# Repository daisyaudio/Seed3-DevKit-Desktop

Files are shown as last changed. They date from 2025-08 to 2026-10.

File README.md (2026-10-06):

# Seed3 Desktop Dev Kit

Seed3 Desktop Dev Kit

## A Synth, Sampler, and Effects Platform for the Daisy Seed3

The Seed3 Desktop Dev Kit is the ultimate Daisy-powered prototyping platform for synths, samplers, and effects. Built around the Seed3, it gives you everything you need to design powerful polysynths, sequenced samplers, and rich DSP effects — all on the same hardware.

With essential audio, MIDI, CV, and control components at your fingertips, the Desktop Dev Kit makes it easy to bring your ideas to life. From stereo audio I/O to hands-on knobs and switches, it's packed with the tools you need to shape your next instrument or effect. Add USB-C connectivity, a microSD card slot, and a dedicated headphone amp, and you've got a ready-made studio workbench for turning concepts into commercial products.

---

## Contents

- [Features](#features)
- [Specifications](#specifications)
- [Getting Started](#getting-started)
- [Making Your Own Project](#making-your-own-project)
- [Hardware Reference](#hardware-reference)
- [Resources & Support](#resources--support)
- [Open-Source Hardware](#open-source-hardware)
- [License](#license)

---

## Features

| Category | Details |
| --- | --- |
| **Audio** | Stereo line-level input and output, with input jack detection |
| **Headphones** | 3.5mm headphone output with volume control |
| **MIDI** | DIN MIDI In, Out, and Thru |
| **CV & Gate** | 2 × CV inputs, 2 × gate inputs, 2 × CV outputs |
| **USB** | USB-C port for power, programming (with the Daisy bootloader), and USB serial |
| **Storage** | microSD slot (with card detect) for firmware updates, samples, presets, configuration, and more |
| **Potentiometers** | 8 × 10kΩ linear (B-taper) |
| **Buttons** | 16 × tactile switches, each with an LED |
| **Toggle Switches** | 2 × toggle switches (1 × ON-OFF-ON, 1 × ON-ON) |

## Specifications

| Parameter | Value |
| --- | --- |
| Processor module | Daisy Seed3 |
| Power | +5V via the Dev Kit's USB-C port |
| Current draw | Firmware dependent |
| Audio codec / sample rate | TAC5242 / up to 32-bit, 192kHz |
| Input impedance | 20kΩ |
| Output impedance | 100Ω |
| CV input range | -5V to +5V |
| CV output range | 0V to +5V |
| Gate input threshold | +0.4V |
| Board dimensions | 197mm × 111mm |
| MIDI connectors | 3 × 5-pin DIN (In, Out, Thru) |

## Getting Started

> [!IMPORTANT]
> This kit has two USB-C ports: one on the **Dev Kit board** (J7, above the Seed3) and one on the **Seed3 module** itself. The steps below say which one to use. Day-to-day, you power, program, and monitor the Dev Kit through the board's USB-C port.

### 1. Install the toolchain

Follow the Daisy [C++ Getting Started guide](https://docs.daisy.audio/tutorials/cpp-dev-env/). It installs the toolchain and clones [DaisyExamples](https://github.com/daisyaudio/DaisyExamples), which includes [libDaisy](https://github.com/daisyaudio/libDaisy) (hardware library) and [DaisySP](https://github.com/daisyaudio/DaisySP) (DSP library).

### 2. Update libDaisy
 
The Desktop Dev Kit template and board support are newer than the copy of libDaisy included with DaisyExamples. From your `DaisyExamples` folder, update libDaisy to its latest version, fetch its own dependencies, and rebuild it:
 
```bash
git submodule update --remote libDaisy
git -C libDaisy submodule update --init --recursive
make -C libDaisy
```
 
The first line moves libDaisy to its latest version. The second fetches libDaisy's own dependencies, such as the STM32 drivers it needs to compile. The last line rebuilds libDaisy, which is required after any update.
 
> [!CAUTION]
> Running `git submodule update --init --recursive` or `git pull --recurse-submodules` from the `DaisyExamples` folder afterwards resets libDaisy to the older version DaisyExamples was built with. If that happens, run the three commands above again.

### 3. Build the template

The starting project for this kit is [`examples/devkits/Desktop-DevKit-UI-Template`](https://github.com/daisyaudio/libDaisy/tree/master/examples/devkits/Desktop-DevKit-UI-Template). It reads every input on the Dev Kit, manages the 16 buttons, 8 pots, and LEDs with libDaisy's UI class, and prints input changes over USB serial. From the `libDaisy` folder:

```bash
cd examples/devkits/Desktop-DevKit-UI-Template
make
```

This creates `Desktop-DevKit-UI-Template.bin` in the template's `build/` folder.

### 4. Install the Daisy bootloader (one time)

The template runs from the Daisy bootloader, using the variant that accepts new programs over the **Dev Kit's** USB-C port. You install the bootloader once, through the **Seed3's** USB-C port:

1. Connect a USB-C cable from your computer to the USB-C port on the Seed3 module.
2. Hold **BOOT**, press and release **RESET**, then release **BOOT**.
3. From the template folder, run:

   ```bash
   make program-boot
   ```

   Or choose the **v6.x (external)** bootloader in the [Daisy Web Programmer](https://flash.daisy.audio/).

You don't need to reinstall the bootloader unless you switch bootloader variants, or want to program an app to the Seed3's internal flash.

### 5. Flash the template

1. Move the USB-C cable to the **Dev Kit's** USB-C port (J7, above the Seed3). This port also powers the board.
2. Press **RESET**, then **BOOT** on the Seed3. The Seed3's USR LED blinks quickly, then pulses slowly, which means it's ready to receive a program.
3. From the template folder, run:

   ```bash
   make program-dfu
   ```

   Or, in the [Daisy Web Programmer](https://flash.daisy.audio/), upload the `Desktop-DevKit-UI-Template.bin` file from the `build/` folder.

### 6. Try it out

Once flashed, the Seed3's USR LED blinks at a steady rate, and:

- Pressing a tactile switch lights its LED.
- CV Out 1 and CV Out 2 output a slow ramp and a saw wave.
- MIDI notes sent to MIDI In are echoed to MIDI Out.
- Audio at the inputs passes straight through to the outputs and the headphone jack.
- A serial monitor connected to the Dev Kit's USB-C port shows a message whenever any input changes.

## Making Your Own Project

Edits only take effect on the Dev Kit after you rebuild and reflash, so start your own project from a copy of the template.

1. Copy the `Desktop-DevKit-UI-Template` folder into your `DaisyExamples` folder and rename it, for example `DaisyExamples/MyInstrument`.
2. In the copied `Makefile`:
   - Set `TARGET` to your project name, for example `TARGET = MyInstrument`.
   - Change `LIBDAISY_DIR` to point to libDaisy from the new location: `LIBDAISY_DIR = ../libDaisy`.
   - To use DaisySP, uncomment the DaisySP line and set `DAISYSP_DIR = ../DaisySP`.
   - Keep the `APP_TYPE=BOOT_SRAM` and `BOOT_BIN` lines. They make your program run from the bootloader you installed in step 4.
3. Write your instrument in `src/main.cpp`, and adjust the button and pot handling in `src/main_page.h`. Audio is processed in `AudioCallback()`: inputs are `in[0][i]` (left) and `in[1][i]` (right), and outputs are `out[0][i]` and `out[1][i]` (see [Audio](#audio)).
4. Rebuild and flash after every change, using the Dev Kit's USB-C port:

   ```bash
   make
   make program-dfu
   ```

   Press **RESET**, then **BOOT**, before each `make program-dfu`.

> [!TIP]
> The template builds with debugging enabled (`DEBUG = 1`, `OPT = -Og`). For release builds, set `DEBUG = 0` and `OPT = -O3` in the Makefile.

## Hardware Reference

The **Ref** column lists each part's reference designator, as printed on the board's silkscreen.

### Pinout

Seed3 Desktop Dev Kit pinout

A printable [Pinout PDF](https://daisy.nyc3.cdn.digitaloceanspaces.com/products/seed-3-desktop/Seed3-Desktop-Dev-Kit-Pinout.pdf) is also available.

### Audio

| Jack | Ref | Signal | Audio Callback |
| --- | --- | --- | --- |
| Input Left | J1 | `AUDIO_IN_L` | `in[0][i]` |
| Input Right | J2 | `AUDIO_IN_R` | `in[1][i]` |
| Output Left | J3 | `AUDIO_OUT_L` | `out[0][i]` |
| Output Right | J4 | `AUDIO_OUT_R` | `out[1][i]` |
| Headphones | J5 | `AUDIO_OUT_L` / `AUDIO_OUT_R` | `out[0][i]` / `out[1][i]` (mirrors the main outputs) |
| Headphone volume | RV1 | — | Analog volume control, not read by the Seed3 |

#### Input Detection

| Jack | Ref | Signal | Seed3 Pin |
| --- | --- | --- | --- |
| Input Left | J1 | `LEFT_DETECT` | D16 |
| Input Right | J2 | `RIGHT_DETECT` | D17 |

### Potentiometers (8-channel multiplexer)

The eight pots are read through a single ADC pin via an 8-channel analog multiplexer (U12). Set the select lines A/B/C to choose a channel, then read `POT_MUX`.

| Signal | Seed3 Pin |
| --- | --- |
| `POT_MUX` (ADC) | D15 |
| `MUX_CTRL_A` | D24 |
| `MUX_CTRL_B` | D25 |
| `MUX_CTRL_C` | D26 |

| Pot | Ref | Mux Channel |
| --- | --- | --- |
| Potentiometer 1 | VR1 | `MUX_CH_0` |
| Potentiometer 2 | VR2 | `MUX_CH_1` |
| Potentiometer 3 | VR3 | `MUX_CH_2` |
| Potentiometer 4 | VR4 | `MUX_CH_3` |
| Potentiometer 5 | VR5 | `MUX_CH_4` |
| Potentiometer 6 | VR6 | `MUX_CH_5` |
| Potentiometer 7 | VR7 | `MUX_CH_6` |
| Potentiometer 8 | VR8 | `MUX_CH_7` |

### Tactile Switches (2 × shift register)

The 16 tactile switches are read through two daisy-chained shift registers (U4, U5).

| Signal | Seed3 Pin |
| --- | --- |
| `SR_LATCH` | D9 |
| `SR_CLK` | D8 |
| `SR_DATA` | D10 |

Switches S1–S16 map to `TAC_SW1`–`TAC_SW16`, arranged in two rows of eight:

| | | | | | | | |
| --- | --- | --- | --- | --- | --- | --- | --- |
| S1 | S2 | S3 | S4 | S5 | S6 | S7 | S8 |
| S9 | S10 | S11 | S12 | S13 | S14 | S15 | S16 |

### LEDs (I²C LED driver)

The 16 LEDs (`LED_1`–`LED_16`, refs D1–D16) sit in the same two rows of eight as the tactile switches, each LED just above its switch (D1 above S1, through D16 above S16), and are driven by a PCA9685 LED driver (U8) over I²C.

| Signal | Seed3 Pin |
| --- | --- |
| `I2C_SCL` | D11 |
| `I2C_SDA` | D12 |

> [!NOTE]
> LED refs D1–D16 are component reference designators, not Seed3 pins.

### Toggle Switches

| Switch | Ref | Signal | Seed3 Pin | Type |
| --- | --- | --- | --- | --- |
| Toggle switch 1 | SW17 | `TOG_1` | D19 | ON-ON |
| Toggle switch 2 | SW18 | `TOG_2_A` / `TOG_2_B` | D28 / D27 | ON-OFF-ON (3-position, two pins) |

### CV & Gates

| Jack | Ref | Signal | Seed3 Pin |
| --- | --- | --- | --- |
| Gate In 1 | J_GATE_IN1 | `GATE_IN1` | D0 |
| Gate In 2 | J_GATE_IN2 | `GATE_IN2` | D18 |
| CV In 1 | J_CV_IN_1 | `CV_IN_1` | D20 |
| CV In 2 | J_CV_IN_2 | `CV_IN_2` | D21 |
| CV Out 1 | J_CV_OUT_1 | `CV_OUT_1` | D23 (DAC channel 1) |
| CV Out 2 | J_CV_OUT_2 | `CV_OUT_2` | D22 (DAC channel 2) |

### MIDI

| Jack | Ref | Signal | Seed3 Pin | Direction |
| --- | --- | --- | --- | --- |
| MIDI Out | J11 | `MIDI_TX` | D13 | Out |
| MIDI In | J10 | `MIDI_RX` | D14 | In |
| MIDI Thru | J8 | `MIDI_RX` | D14 | Mirrors MIDI In |

### microSD (SDMMC, 4-bit)

| Signal | Seed3 Pin |
| --- | --- |
| `SDMMC_CK` | D6 |
| `SDMMC_CMD` | D5 |
| `SDMMC_D0` | D4 |
| `SDMMC_D1` | D3 |
| `SDMMC_D2` | D2 |
| `SDMMC_D3` | D1 |
| `SDMMC_DETECT` | D7 |

### USB-C

The Dev Kit's USB-C port (J7) powers the board and connects to the Seed3's external USB peripheral. It is separate from the USB-C port on the Seed3 module.

| Signal | Seed3 Pin |
| --- | --- |
| `USB_OTG_HS_N` | D29 |
| `USB_OTG_HS_P` | D30 |

## Resources & Support

- **Product Page:** [Seed3 Desktop Dev Kit](https://daisy.audio/products/seed-3-desktop-dev-kit)
- **Documentation:** [docs.daisy.audio](https://docs.daisy.audio/product/Seed3-Desktop-Dev-Kit/)
- **Community Forum:** [community.daisy.audio](https://community.daisy.audio)
- **Discord:** [Daisy Discord](https://discord.gg/ByHBnMtQTR)
- **Issues:** Report bugs or hardware errata via this repository's [Issues](../../issues) tab.

### Design Files

- [Schematic (PDF)](https://daisy.nyc3.cdn.digitaloceanspaces.com/products/seed-3-desktop/ES-Seed3-DevKit-Desktop-Rev3.pdf)
- [Bill of Materials (CSV)](https://daisy.nyc3.cdn.digitaloceanspaces.com/products/seed-3-desktop/Seed3-DevKit-Desktop_Rev4-bom.csv)
- [Pinout (PDF)](https://daisy.nyc3.cdn.digitaloceanspaces.com/products/seed-3-desktop/Seed3-Desktop-Dev-Kit-Pinout.pdf)
- [KiCad Design Files](https://github.com/daisyaudio/Seed3-DevKit-Desktop/releases/latest)

---

## Open-Source Hardware

Open Source Hardware logo

The Desktop Dev Kit is open-source hardware, built to the [Open Source Hardware Definition](https://www.oshwa.org/definition/) published by the Open Source Hardware Association (OSHWA). The schematics, PCB layouts, bill of materials, and KiCad source files are published so that you can study, modify, manufacture, and sell your own designs based on them.

## License

Copyright © 2026 Qu-Bit Electronix, Inc. (dba Daisy)

The hardware design files in this repository are licensed under the **CERN Open Hardware Licence Version 2 – Permissive** ([CERN-OHL-P-2.0](https://ohwr.org/cern_ohl_p_v2.pdf)).

Subject to the terms of that licence, you may:

- Use, study, copy, modify, and distribute these designs and any products made from them.
- Incorporate these designs, in whole or in part, into closed-source and commercial products.

These designs are provided "as is", without warranty of any kind, express or implied. See [LICENSE](LICENSE.txt) for the full licence text, including the disclaimer of warranty and limitation of liability.

Firmware and software, including [libDaisy](https://github.com/daisyaudio/libDaisy) and [DaisySP](https://github.com/daisyaudio/DaisySP), are licensed separately under the terms included in their respective repositories.

SPDX-License-Identifier: CERN-OHL-P-2.0

### Trademarks

DAISY® is a trademark of Qu-Bit Electronix, Inc., registered in the United States. CERN-OHL-P-2.0 grants a license to the copyright and related rights in these designs. It does not grant any right or license to use the DAISY name, logos, product names, or other trademarks of Qu-Bit Electronix, Inc.

Products, derivative designs, and related materials made from these designs may not:

- Use the DAISY name or logo, or any confusingly similar name or mark, in a product name, model number, brand, domain name, or marketing material.
- Reproduce the DAISY name or logo on a PCB silkscreen, front panel, enclosure, packaging, or documentation, except where needed to keep the required licence notices.
- State or imply that the product is made, endorsed, sponsored, certified, or supported by Qu-Bit Electronix, Inc.

You may make truthful, factual statements about compatibility or origin, such as "based on the Seed3 Desktop Dev Kit design" or "compatible with the Daisy Seed3", provided the statement does not suggest affiliation or endorsement. If you redistribute or sell products derived from these designs, remove the DAISY name and logo from the silkscreen and other artwork before manufacture.

For trademark licensing or permission requests, contact Qu-Bit Electronix, Inc. through [daisy.audio/pages/support](https://daisy.audio/pages/support).

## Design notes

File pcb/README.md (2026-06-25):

# Changelog

## Rev4

- Added missing diode to MIDI input circuit

## Rev3

- Removed components from audio input circuit that introduced noise: R64, R65, D21, D22, D23, D24
- Connected switching connection on CV Input jacks to GND to prevent idling at non-0V
- Added silk screen indications for software mapping to Daisy for all pins/peripheral information.
- Swapped CV out 1 and 2 from the seed so that the software channel matches the hardware label

## Rev2

- Fixed INH pin on CD4051 to be properly connected to GND.
- Fixed LED OE pin on PCA9685 to be properly connected to GND so it is always on.
- Huge rework of power supply circuit
  - USB +5V now goes to a boost to generate +9V
  - +9V is split to provide DSY_VIN, +9V_A
  - +9V_A now powers an LD1117-5V to generate a more reliable +5V (for headphones, DAC MCP6002, and CV input ref voltage)
- AREF_+2V5 has been replaced with +4v5 generated from buffered +9V_A
- Added clamping diodes (1N5817) to the audio input detection to help protect from higher level audio potentially damaging the GPIO.
- Added explicit, "C0G" in value field for the few caps that should be that
- Added series AC coupling cap to input of the line out circuit (to better match, the already tested Pedal circuit).
- Added series 100R resistor to the output of the line out circuit
- Added a 10k to GND after the output coupling cap so the HPF is fixed (once again, to match the pedal circuit)
- Updated rev text to rev2
- Moved Open hardware logo to below the CV/Gate jacks (new beefy power circuits occupied previous location)
- Added some more vias to GND where it makes sense.
- Updated QR code to point to: <https://electro-smith.com/seed3-desktop-redirect>

## Rev1

Original Hardware

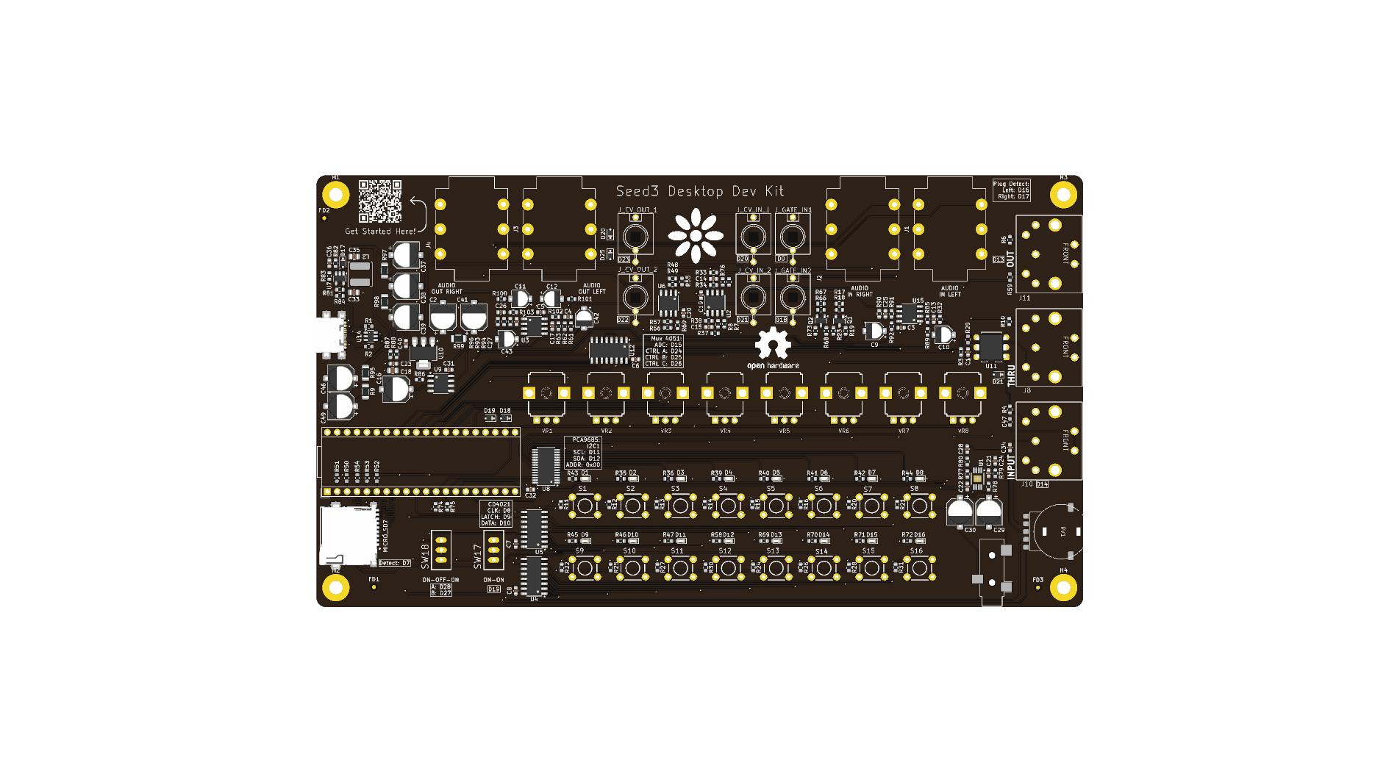
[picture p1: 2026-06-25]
pcb/ES-Seed3-Devkit-Desktop-Rev4/review/2026-06-18/board-render/render_top.png

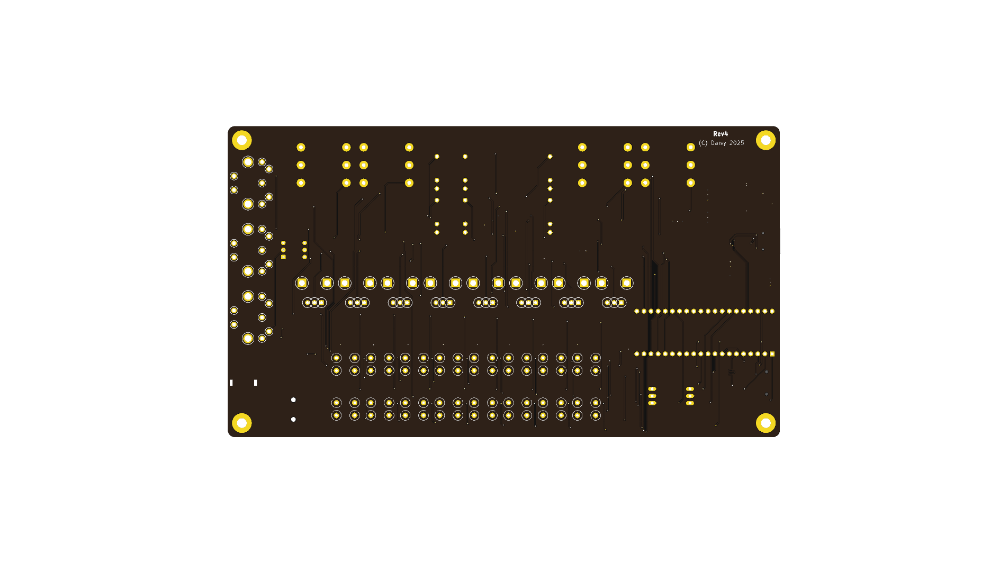
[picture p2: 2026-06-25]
pcb/ES-Seed3-Devkit-Desktop-Rev4/review/2026-06-18/board-render/render_bottom.png

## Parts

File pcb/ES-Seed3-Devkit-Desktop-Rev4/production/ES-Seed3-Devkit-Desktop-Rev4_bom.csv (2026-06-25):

Value | Reference | Footprint | Qty | AVL_Part_Number
 | J_CV_IN_1,J_CV_IN_2,J_CV_OUT_1,J_CV_OUT_2,J_GATE_IN1,J_GATE_IN2 | Electrosmith-Interface:S_JACK | 6
0R | R84 | Resistor_SMD:R_0603_1608Metric | 1 | 0R R0603
1NF | C14,C15 | Capacitor_SMD:C_0603_1608Metric | 2 | 1NF C0603
1UF | C21 | Capacitor_SMD:C_0603_1608Metric | 1 | 1UF C0603
3R3 | R9,R95,R97,R98,R99 | Resistor_SMD:R_1206_3216Metric | 5 | 3R3
10UF MLCC | C18,C33,C35 | Capacitor_SMD:C_0805_2012Metric | 3 | 10UF MLCC C0805
10R | R6,R10,R29,R59 | Resistor_SMD:R_0603_1608Metric | 4 | 10R R0603
10UF | C9,C10,C11,C12,C42,C43 | Capacitor_SMD:CP_Elec_4x5.8 | 6 | 10UF
100NF | C1,C3,C5,C6,C7,C8,C19,C20,C22,C23,C31,C32,C34,C40,C47 | Capacitor_SMD:C_0603_1608Metric | 15 | 100NF C0603
100R | R23,R55,R60,R73,R102,R103 | Resistor_SMD:R_0603_1608Metric | 6 | 100R R0603
100UF | C2,C16,C29,C30,C37,C38,C39,C41,C46,C49 | Capacitor_SMD:CP_Elec_6.3x7.7 | 10 | 100UF
220R | R4 | Resistor_SMD:R_0603_1608Metric | 1 | 220R R0603
270R | R3 | Resistor_SMD:R_0603_1608Metric | 1 | 270R R0603
470NF | C24,C28 | Capacitor_SMD:C_0603_1608Metric | 2 | 470NF C0603
750R | R62,R93 | Resistor_SMD:R_0603_1608Metric | 2 | 750R R0603
1K | R89,R92 | Resistor_SMD:R_0603_1608Metric | 2 | 1K R0603
2K | R35,R36,R39,R40,R41,R42,R43,R44,R45,R46,R47,R58,R69,R70,R71,R72,R74,R75 | Resistor_SMD:R_0603_1608Metric | 18 | 2K R0603
5K1 | R1,R2 | Resistor_SMD:R_0603_1608Metric | 2 | 5K1 R0603
10K | R11,R12,R13,R14,R15,R16,R19,R20,R21,R22,R24,R25,R26,R27,R28,R30,R31,R61,R68,R83,R85,R86,R87,R88,R91,R96,R100,R101 | Resistor_SMD:R_0603_1608Metric | 28 | 10K R0603
20K | R32,R63,R90,R94 | Resistor_SMD:R_0603_1608Metric | 4 | 20K R0603
22K | R79,R80 | Resistor_SMD:R_0603_1608Metric | 2 | 22K R0603
33K | R5,R7,R34,R38,R77,R78 | Resistor_SMD:R_0603_1608Metric | 6 | 33K R0603
47K | R50,R51,R52,R53,R54 | Resistor_SMD:R_0603_1608Metric | 5 | 47K R0603
62K | R49,R57,R82 | Resistor_SMD:R_0603_1608Metric | 3 | 62K R0603
100K | R8,R17,R33,R37,R66,R76 | Resistor_SMD:R_0603_1608Metric | 6 | 100K R0603
120K | R48,R56 | Resistor_SMD:R_0603_1608Metric | 2 | 120K R0603
1M | R18,R67,R81 | Resistor_SMD:R_0603_1608Metric | 3 | 1M R0603
470PF | C4,C26 | Capacitor_SMD:C_0603_1608Metric | 2 | 470PF C0603
560PF | C36 | Capacitor_SMD:C_0603_1608Metric | 1 | 560PF C0603
1N5817WS | D17,D18,D19,D20,D21,D25 | Diode_SMD:D_SOD-323F | 6 | 1N5817WS
330PF C0G | C13,C25 | Capacitor_SMD:C_0603_1608Metric | 2 | 330PF C0G C0603
470PF C0G | C17,C27 | Capacitor_SMD:C_0603_1608Metric | 2 | 470PF C0G C0603
6.8uH 2.9A | L2 | Inductor_SMD:L_TDK_VLS6045EX_VLS6045AF | 1 | 6.8uH 2.9A
AudioJack3_Switch | J1,J2,J3,J4 | Connector_Audio:Jack_6.35mm_Neutrik_NMJ6HCD2_Horizontal | 4 | AudioJack3_Switch
AudioJack3_Switch_HEADPHONE | J5 | Connector_Audio:Jack_3.5mm_CUI_SJ-3523-SMT_Horizontal | 1 | AudioJack3_Switch_HEADPHONE
CD4051B | U12 | Package_SO:SOIC-16_3.9x9.9mm_P1.27mm | 1 | CD4051B
CD4021BM96 | U4,U5 | Package_SO:SOIC-16_3.9x9.9mm_P1.27mm | 2 | CD4021BM96
DIN_MIDI_5P | J8,J10,J11 | parts-for-kicad:57PC5F | 3 | DIN_MIDI_5P
Electrosmith_Daisy_Seed_Rev4 | A1 | Module:Electrosmith_Daisy_Seed | 1 | Electrosmith_Daisy_Seed_Rev4
H11L1 | U11 | Package_DIP:DIP-6_W7.62mm | 1 | H11L1
LD1117S50TR_SOT223 | U10 | Package_TO_SOT_SMD:SOT-223-3_TabPin2 | 1 | LD1117S50TR_SOT223
LED | D1,D2,D3,D4,D5,D6,D7,D8,D9,D10,D11,D12,D13,D14,D15,D16 | LED_SMD:LED_0603_1608Metric | 16 | LED
LMR62421XMF | U7 | Package_TO_SOT_SMD:SOT-23-5 | 1 | LMR62421XMF
MCP6002-xSN | U2,U6,U9 | Package_SO:SOIC-8_3.9x4.9mm_P1.27mm | 3 | MCP6002-xSN
MMBT3904 | Q1,Q2 | Package_TO_SOT_SMD:SOT-23 | 2 | MMBT3904
OPA1652 | U3,U15 | Package_SO:SOIC-8_3.9x4.9mm_P1.27mm | 2 | OPA1652
P-10K-B-R | VR1,VR2,VR3,VR4,VR5,VR6,VR7,VR8 | parts-for-kicad:9MM_SNAP-IN_POT_SILK | 8 | P-10K-B-R
PCA9685PW | U8 | Package_SO:TSSOP-28_4.4x9.7mm_P0.65mm | 1 | PCA9685PW
PTH Mini Button | S1,S2,S3,S4,S5,S6,S7,S8,S9,S10,S11,S12,S13,S14,S15,S16 | parts-for-kicad:TL1105SPF250Q_SILK | 16 | PTH Mini Button
R_Potentiometer_Dual_Separate | RV1 | shnsly:Rotary Pot RK10J | 1 | R_Potentiometer_Dual_Separate
TF-01A | MICRO_SD7 | TF-01A:TF-01A | 1 | TF-01A
TOGGLE_ON-ON_PIP3 | SW17 | Electrosmith-Interface:TOGGLE_ON-ON | 1 | TOGGLE_ON-ON_PIP3
TOGGLE_ON_OFF_ON_PIP2 | SW18 | Electrosmith-Interface:TOGGLE_ON_OFF_ON | 1 | TOGGLE_ON_OFF_ON_PIP2
TPA6110A2DGN | U1 | Package_SO:HVSSOP-8-1EP_3x3mm_P0.65mm_EP1.57x1.89mm | 1 | TPA6110A2DGN
USB4110GFA | J7 | USB4110GFA:GCT_USB4110GFA | 1 | USB4110GFA
USBLC6-2SC6 | U14 | Package_TO_SOT_SMD:SOT-23-6 | 1 | USBLC6-2SC6

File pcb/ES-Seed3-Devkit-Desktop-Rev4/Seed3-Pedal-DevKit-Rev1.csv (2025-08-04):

Id | Designator | Footprint | Quantity | Designation | Supplier and ref
1 | R46,R8,R48,R13,R72,R27,R76,R16,R55 | R_0603_1608Metric | 9 | 100R
2 | FD3,FD1,FD2 | Fiducial_1mm_Mask2mm | 3 | FIDUCIAL
3 | C46 | C_0603_1608Metric | 1 | 10NF
4 | R61,R57,R62,R29,R28,R59,R63 | R_0603_1608Metric | 7 | 10R
5 | SW4,SW3 | TL3301SPF160QJ | 2 | SMT Mini Button
6 | C30,C9,C28,C8 | C_0603_1608Metric | 4 | 1NF
7 | R77,R26,R56,R22,R14,R69,R65,R5,R19,R17,R68,R70,R64 | R_0603_1608Metric | 13 | 10K
8 | Q1,Q5 | SOT-23 | 2 | 3904
9 | C5,C38 | C_0603_1608Metric | 2 | 100PF
10 | C31,C47,C33,C20,C2,C25,C34,C22,C4,C16,C17,C1 | C_0603_1608Metric | 12 | 100NF
11 | R50,R51,R52,R54,R53 | R_0603_1608Metric | 5 | 47K
12 | C27,C24,C43,C36,C14,C21,C39,C13,C41,C23 | CP_Elec_6.3x7.7 | 10 | 100UF
13 | U3,U10,U9 | SOIC-8_5.275x5.275mm_P1.27mm | 3 | OPA1652
14 | FB2,FB5,FB8,FB1,FB9,FB10,FB3,FB4,FB7 | R_0603_1608Metric | 9 | FERRITE_BEAD_0603
15 | R2,R1 | R_0603_1608Metric | 2 | 5K1
16 | H1,H2,H3,H4 | MountingHole_3.5mm_Pad | 4 | MOUNT-PAD-ROUND3.5
17 | LOGO1 | OSHW-LOGO-L_TEXT | 1 | OSHW-LOGO
18 | J5,J2,J6,J3,J4 | TRS_JACK_WQP-PJ609B | 5 | JACK_TRS_SWITCHING
19 | C12,C37 | C_0603_1608Metric | 2 | 33NF
20 | J11,J1,J10 | 57PC5F | 3 | DIN_MIDI_5P
21 | VR3,VR5,VR1,VR4,VR6,VR2 | 9MM_SNAP-IN_POT_SILK_PIP | 6 | P-10K-B-R-PIP
22 | R44,R9,R43,R10,R24,R23,R40,R25 | R_0603_1608Metric | 8 | 2K
23 | R60 | R_0603_1608Metric | 1 | 20K
24 | SW2,SW6 | TOGGLE_SILK_PIP3 | 2 | TOGGLE_ON-ON_PIP3
25 | U8 | SOT-223-3_TabPin2 | 1 | LD1117-5V
26 | R21,R71 | R_0603_1608Metric | 2 | 4K7
27 | R7,R15,R18 | R_0603_1608Metric | 3 | 1M
28 | C29,C48,C10,C42,C7,C35,C6,C3 | CP_Elec_4x5.8 | 8 | 10uF
29 | D6,D5 | D_SOD-323 | 2 | NSR1020MW2T3G
30 | LED1 | LED_D5.0mm | 1 | LED
31 | R11,R74 | R_0603_1608Metric | 2 | 15K
32 | A1 | Electrosmith_Daisy_Seed | 1 | Electrosmith_Daisy_Seed_Rev4
33 | C11,C32 | C_0603_1608Metric | 2 | 270PF
34 | U6,U5 | RELAY-SMD_G6K-2F-Y | 2 | G6K-2F-Y-TR DC3
35 | C26,C15 | C_0805_2012Metric | 2 | 10UF
36 | R75,R12 | R_0603_1608Metric | 2 | 24K
37 | R58,R20 | R_0603_1608Metric | 2 | 3K3
38 | D3,D4 | D_SOD-323 | 2 | 1N4148
39 | U11 | DIP-6_W7.62mm | 1 | H11L1
40 | FSW_1,FSW_2 | S02P | 2 | M12 SPST Footswitch Assembly
41 | U14 | SOT-23-6 | 1 | USBLC6-2SC6
42 | C55 | C_0603_1608Metric | 1 | 1UF
43 | SW1 | TOGGLE_SILK_PIP3 | 1 | TOGGLE_ON_OFF_ON_PIP2
44 | R3 | R_0603_1608Metric | 1 | 270R
45 | C18,C19 | CP_Elec_4x5.8 | 2 | 10UF
46 | LED2 | LED_D5.0mm-4_RGB_Wide_Pins | 1 | LED_RKBG
47 | U1 | SOIC-8_5.275x5.275mm_P1.27mm | 1 | MCP6002-xSN
48 | L2 | SDR0805 | 1 | SDR0805-102KL
49 | U7 | MEM2061-01-188-00-A_GCT | 1 | MICRO_SD_CARD
50 | J8 | BarrelJack_Wuerth_6941xx301002 | 1 | Barrel_Jack_Switch
51 | U4 | USB-C-SMD_G-SWITCH_GT-USB-7010ASV | 1 | GT-USB-7010ASV
52 | R4 | R_0603_1608Metric | 1 | 220R

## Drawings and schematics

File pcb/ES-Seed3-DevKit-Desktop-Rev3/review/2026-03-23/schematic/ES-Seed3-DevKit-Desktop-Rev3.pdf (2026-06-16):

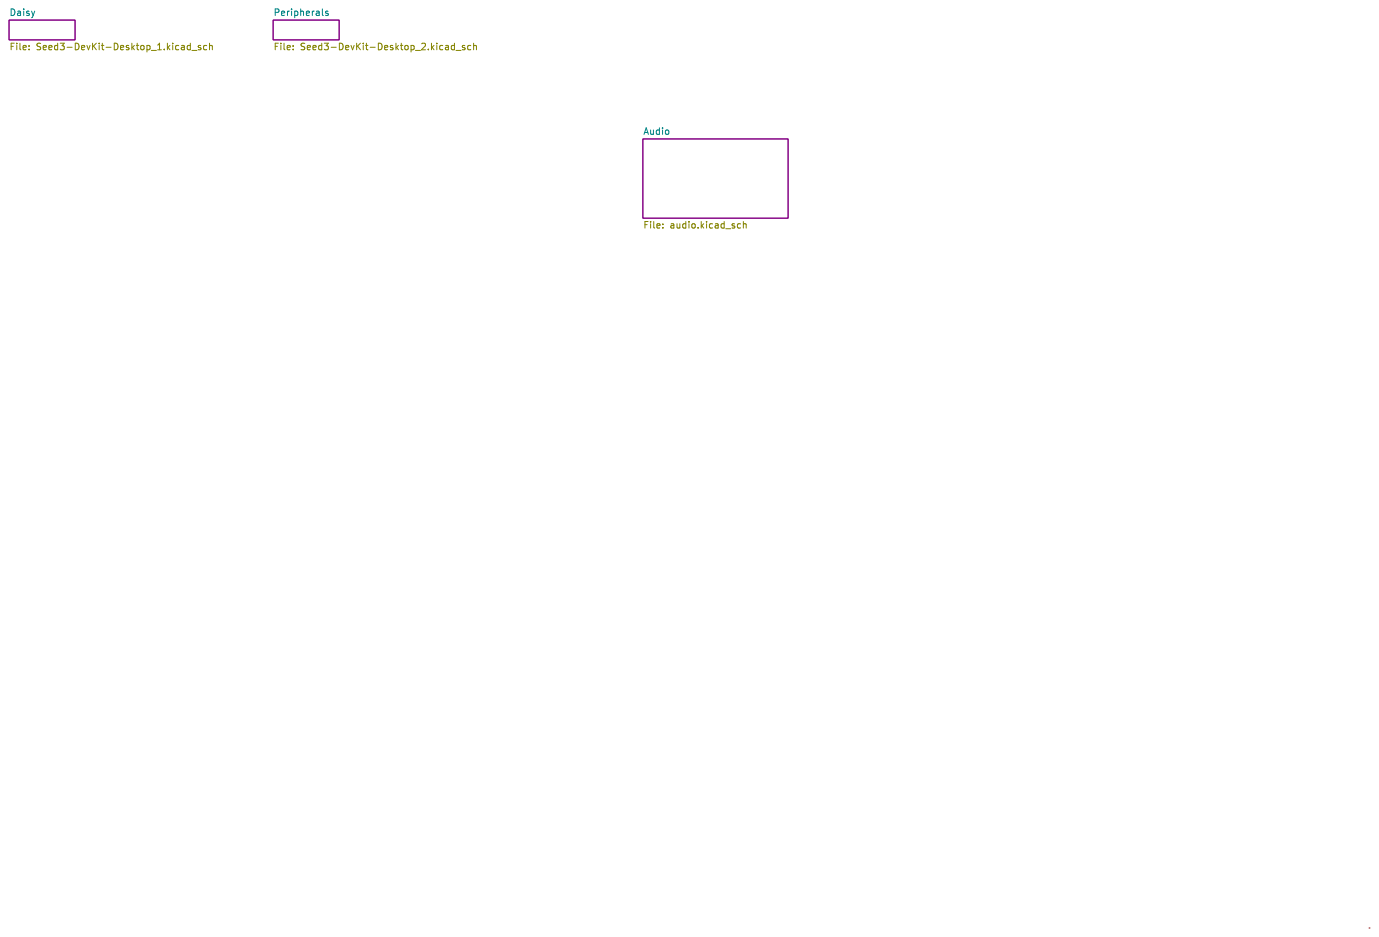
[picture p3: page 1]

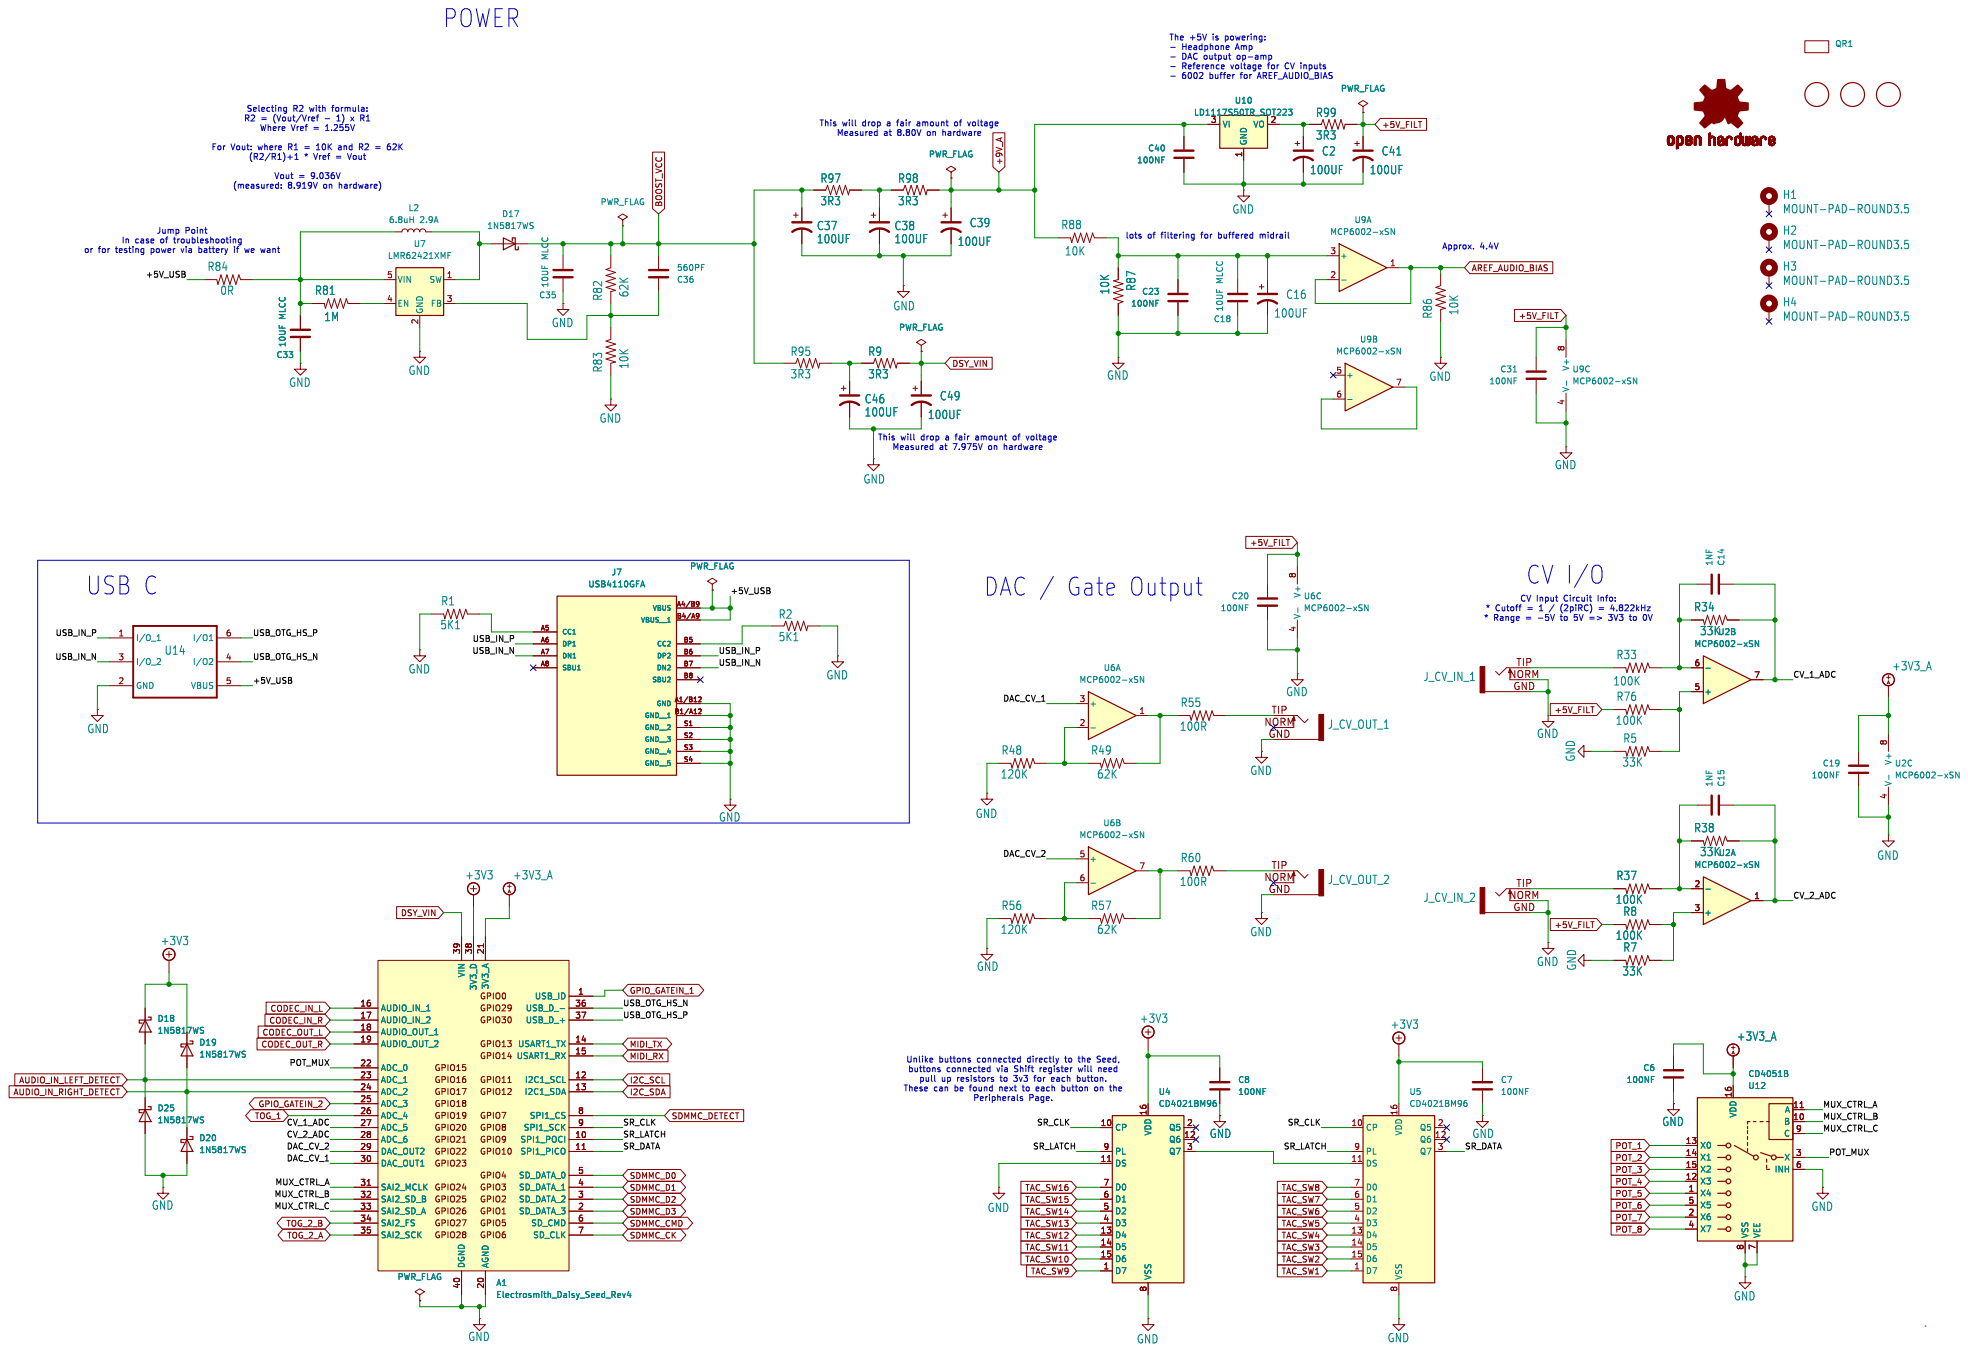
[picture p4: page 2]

The +5V is powering: - Headphone Amp
TAC_SW14 +9V_A

- DAC output op-amp
- Reference voltage for CV inputs
- 6002 buffer for AREF_AUDIO_BIAS

For Vout: where R1 = 10K and R2 = 62K

In case of troubleshooting

or for testing power via battery if we want USB C

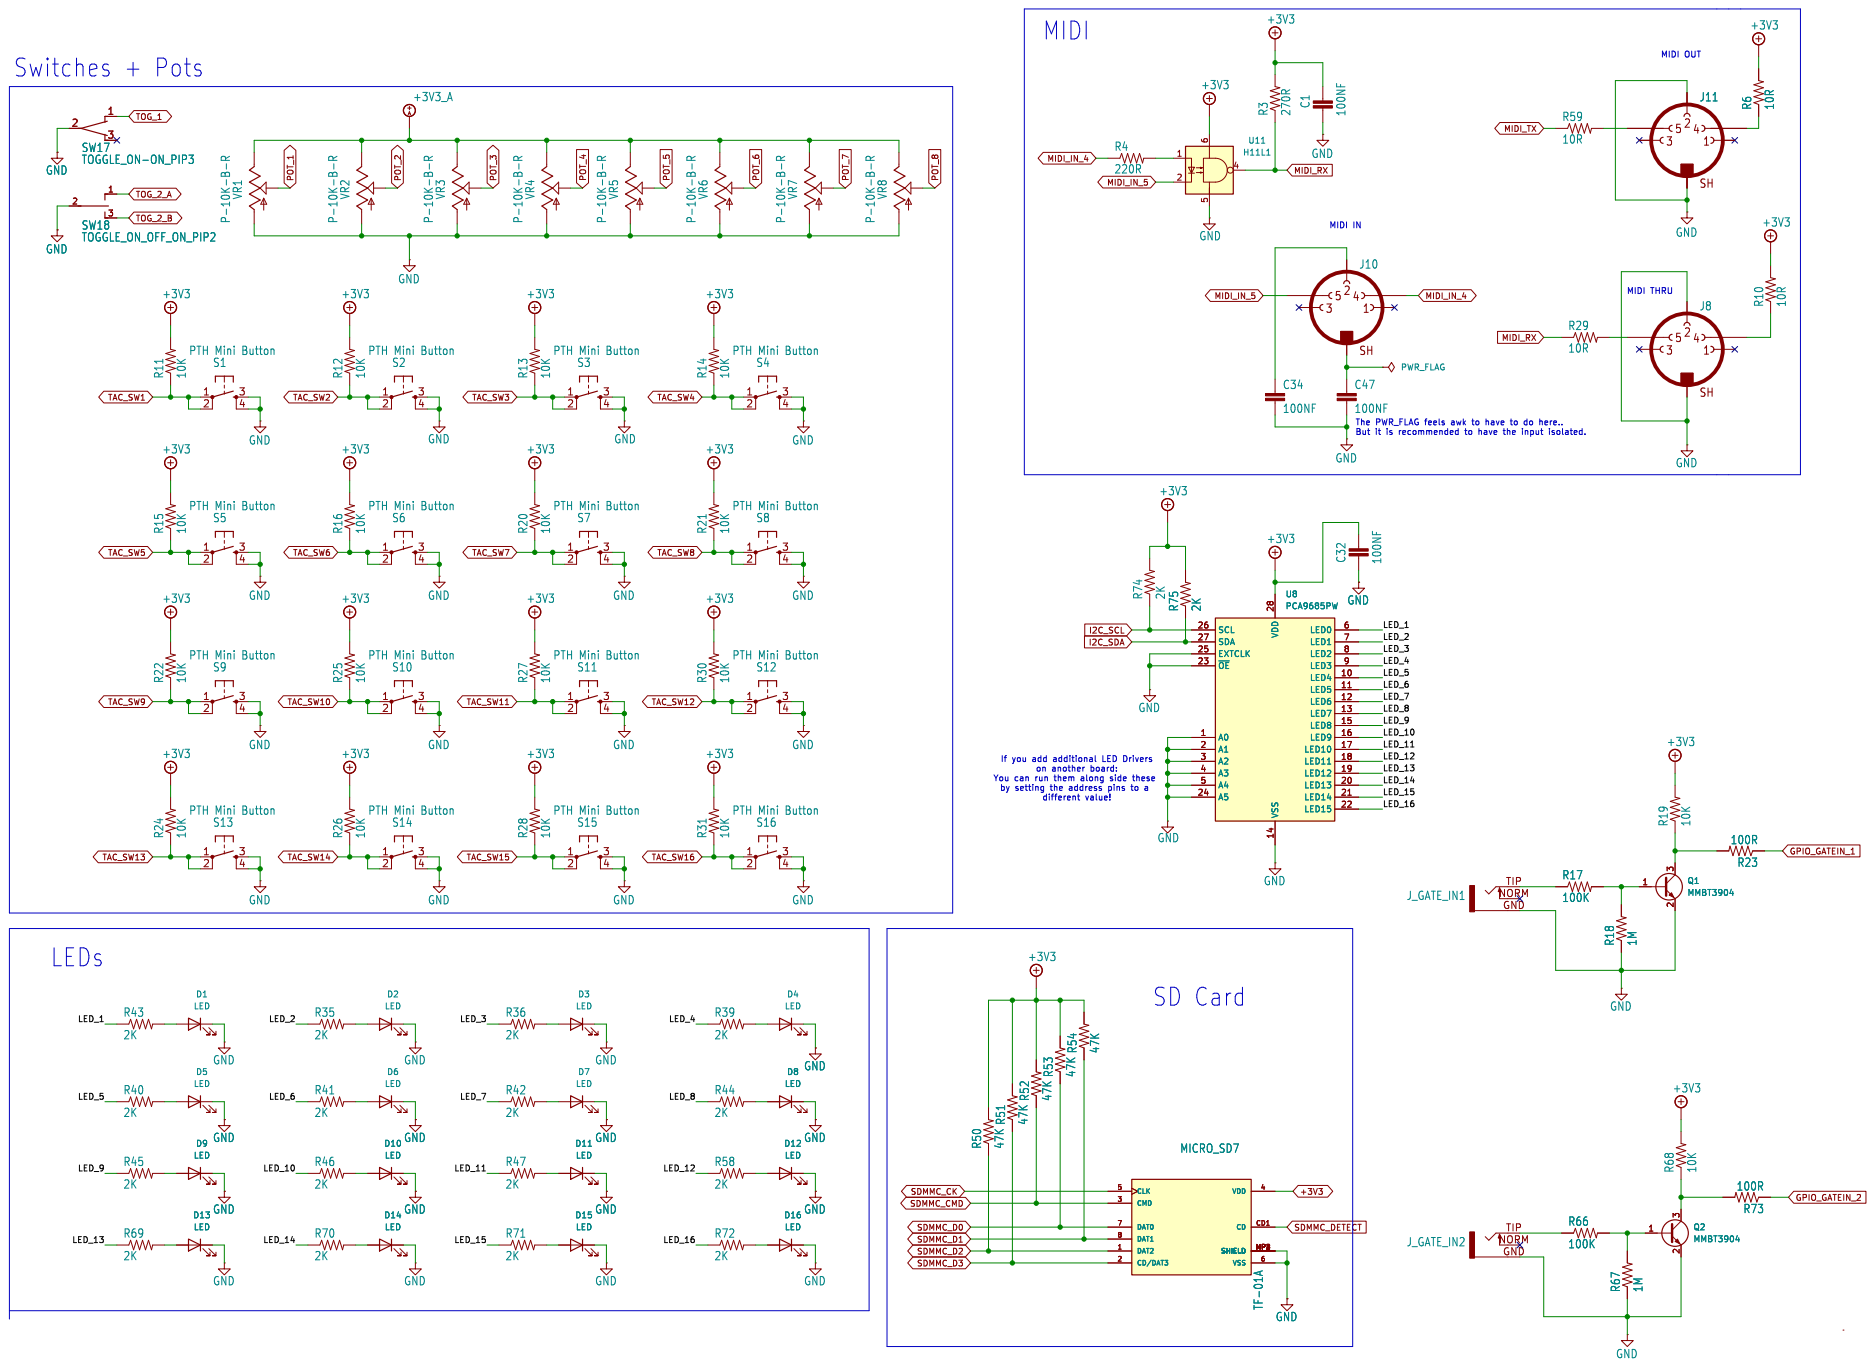
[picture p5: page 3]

MIDI OUT MIDI THRU

by setting the address pins to a

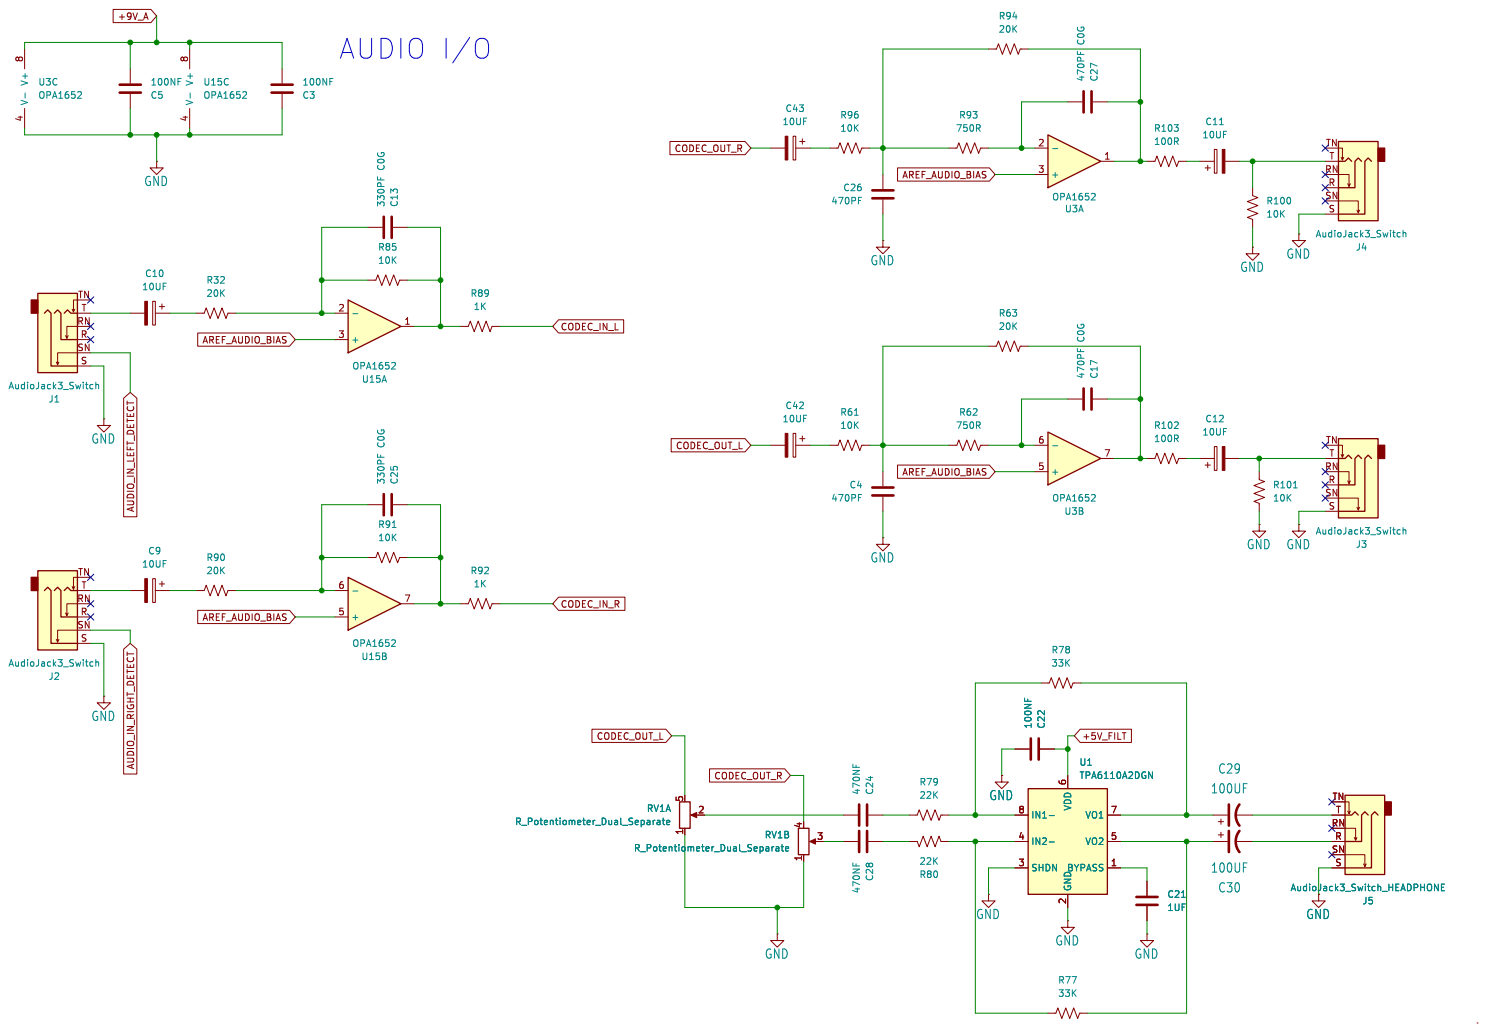
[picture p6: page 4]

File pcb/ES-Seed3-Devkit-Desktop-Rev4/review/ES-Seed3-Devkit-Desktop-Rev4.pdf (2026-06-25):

Peripherals File: Seed3-DevKit-Desktop_2.kicad_sch

Daisy File: Seed3-DevKit-Desktop_1.kicad_sch

Audio

File: audio.kicad_sch

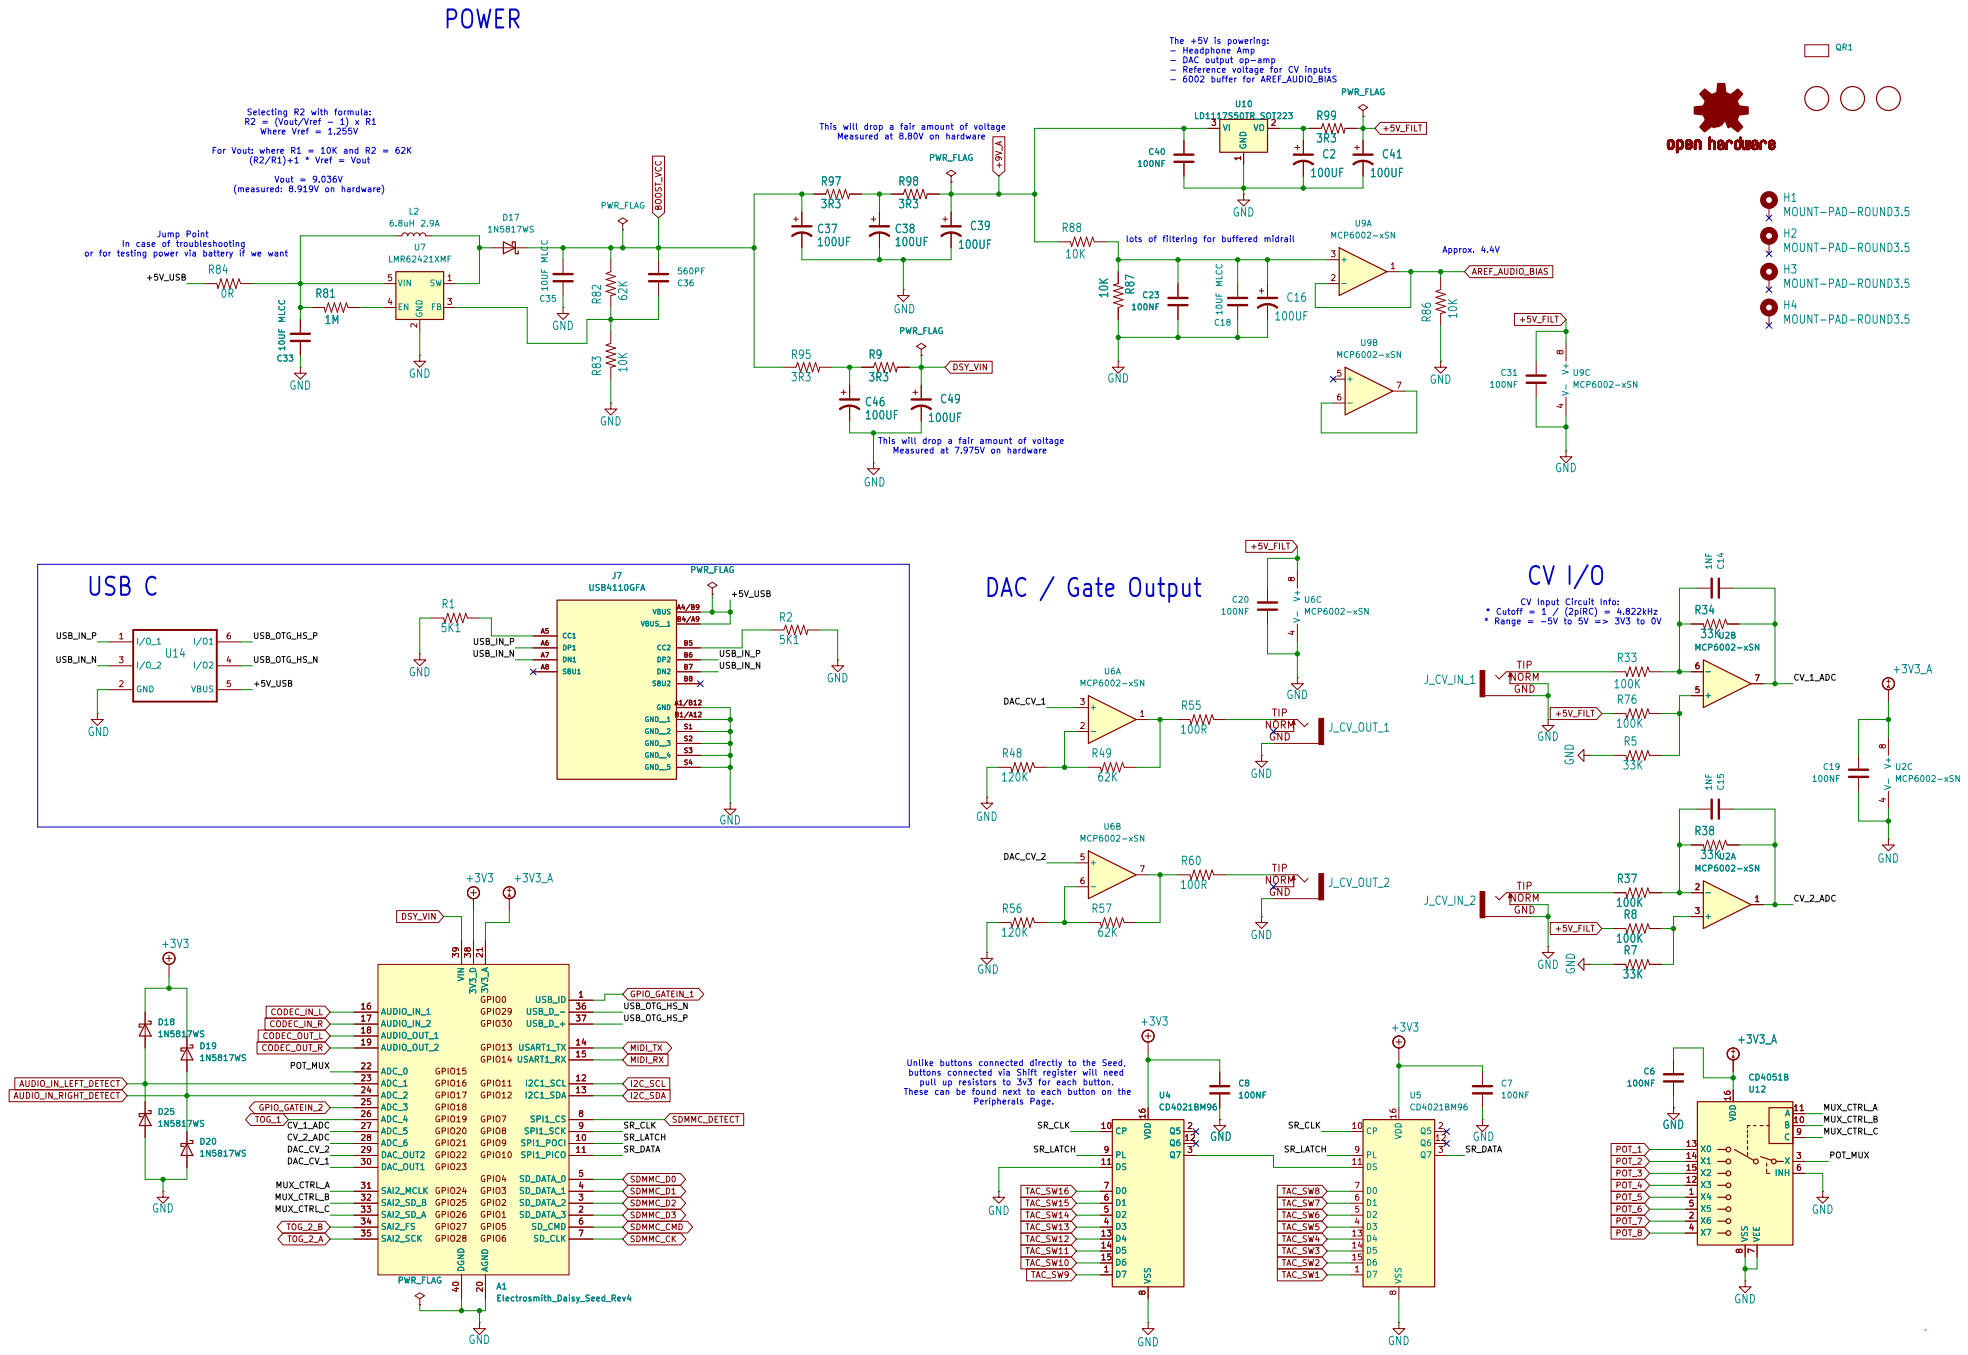
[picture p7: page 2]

lots of filtering for buffered midrail POWER

The +5V is powering: - Headphone Amp - DAC output op-amp - Reference voltage for CV inputs - 6002 buffer for AREF_AUDIO_BIAS

Selecting R2 with formula: R2 = (Vout/Vref - 1) x R1 Where Vref = 1.255V

This will drop a fair amount of voltage Measured at 8.80V on hardware
PWR_FLAG R98

For Vout: where R1 = 10K and R2 = 62K
LMR62421XMF GND

In case of troubleshooting

or for testing power via battery if we want USB C

This will drop a fair amount of voltage Measured at 7.975V on hardware

8 PL 9 CP 10 DS 11 Q6 12 D4 13 D5 14 D6 15 VDD 16 U4CD4021BM96 GNDR7

8 PL 9 CP 10 DS 11 Q6 12 D4 13 D5 14 D6 15 VDD 16 U5CD4021BM96 +3V3_A

SR_CLK Unlike buttons connected directly to the Seed, buttons connected via Shift register will need

pull up resistors to 3v3 for each button. These can be found next to each button on the Peripherals Page.

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

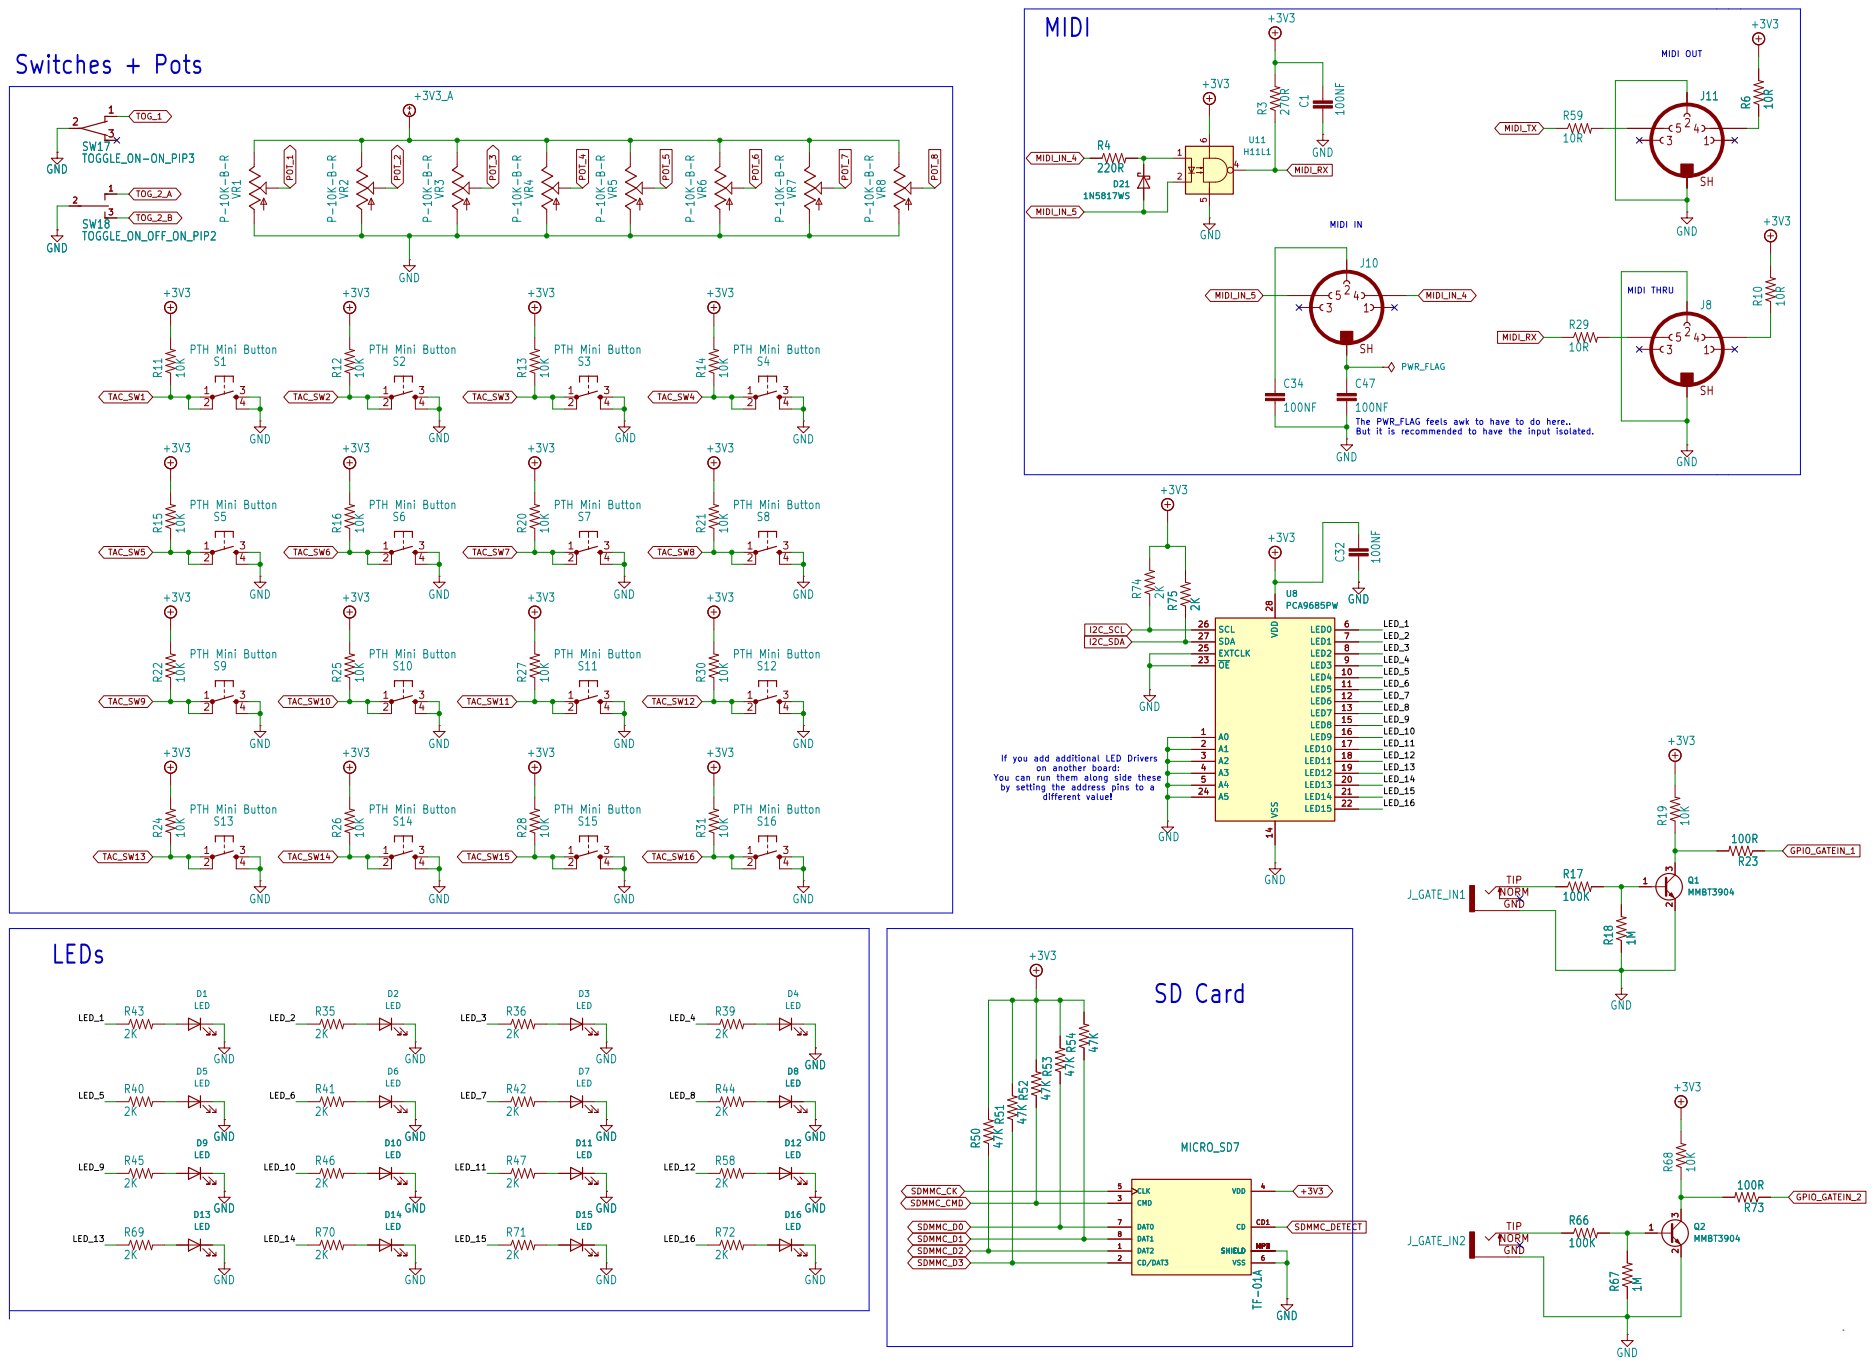
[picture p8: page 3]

The PWR_FLAG feels awk to have to do here.. But it is recommended to have the input isolated. MIDI

If you add additional LED Drivers on another board: You can run them along side these by setting the address pins to a different value! LEDs

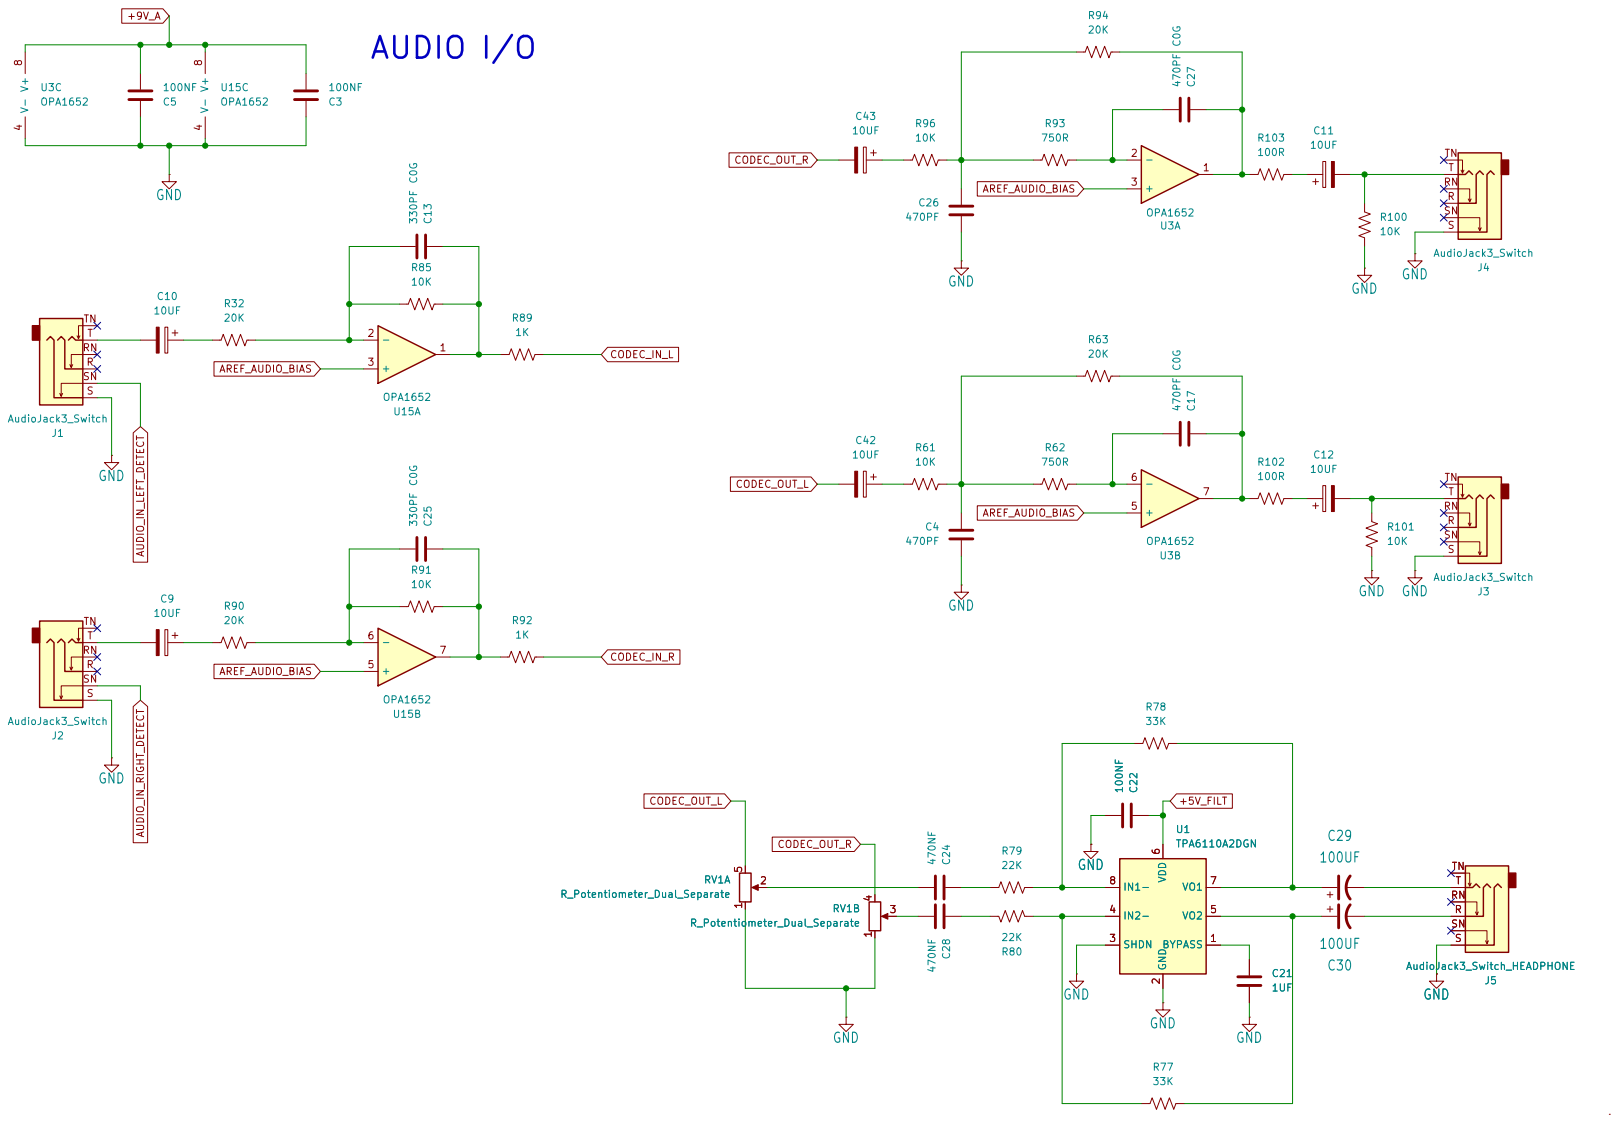
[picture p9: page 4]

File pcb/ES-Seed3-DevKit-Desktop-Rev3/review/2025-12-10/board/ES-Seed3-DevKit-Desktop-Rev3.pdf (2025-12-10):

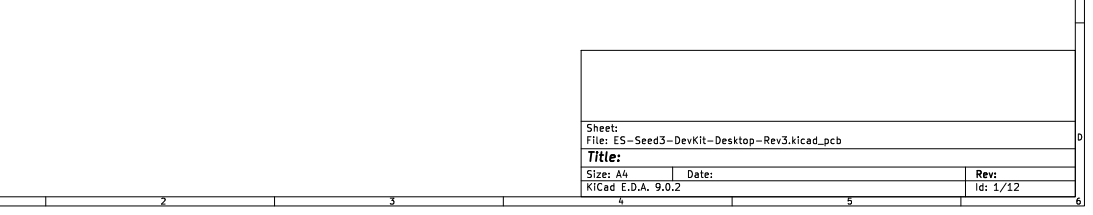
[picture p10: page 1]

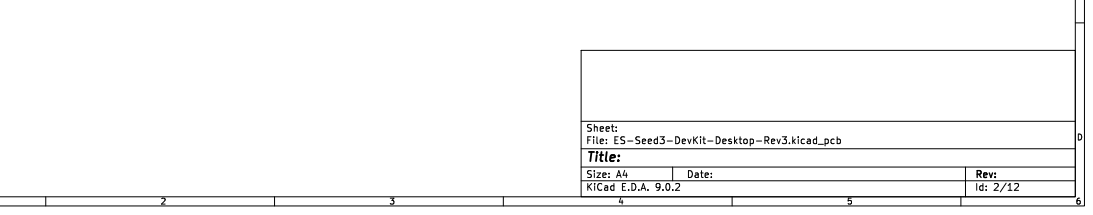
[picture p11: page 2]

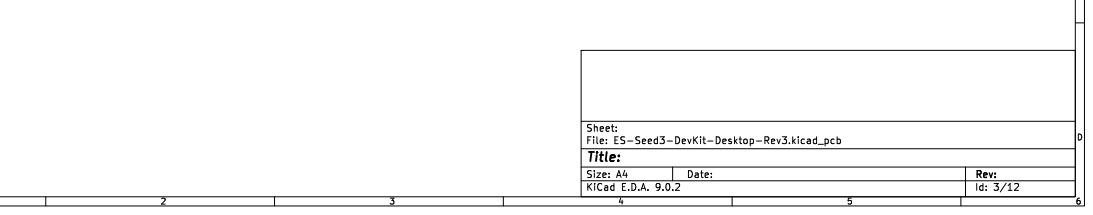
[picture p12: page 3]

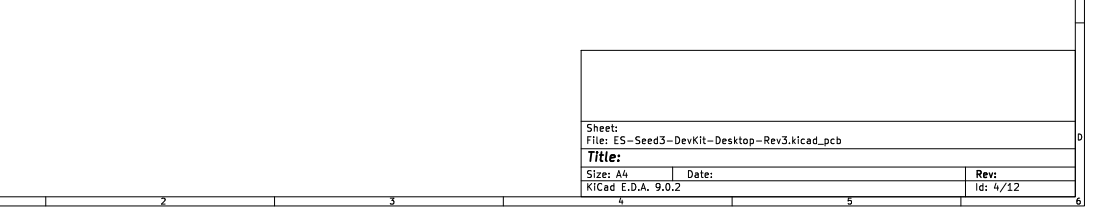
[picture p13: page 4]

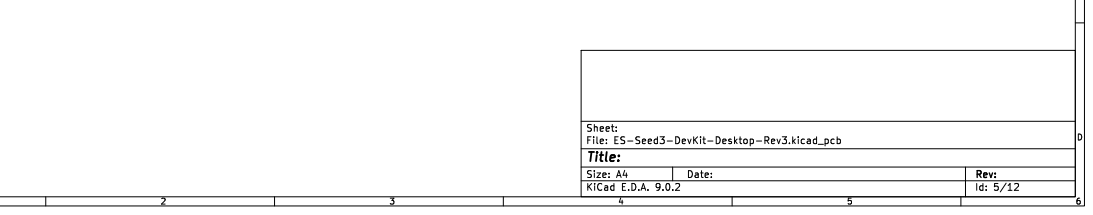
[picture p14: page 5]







Plated Board Edge: Not specified

Edge card connectors: 1 0 mm 0 mm

Layer Name B.Cu | copper | Matte | Thickness (mm) | | 1 1 Bottom Solder Mask F.Cu | 0 FR4

Top Solder Mask Bottom Solder Paste | 0.035 mm | 1 1 | Loss Tangent 0 mm 0 Color 00


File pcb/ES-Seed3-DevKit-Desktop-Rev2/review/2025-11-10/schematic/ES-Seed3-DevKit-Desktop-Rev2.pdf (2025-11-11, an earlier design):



At the moment, the +5V is powering: - Headphone Amp

- DAC output op-amp
- Reference voltage for CV inputs

For Vout: where R1 = 10K and R2 = 62K

In case of troubleshooting

* Range = -5V to 5V => 3V3 to 0V CV I/O


MIDI OUT MIDI THRU

by setting the address pins to a


I updated these to be gain of 2. However, I'm not really sure how the math works out for the other two values.. So, I may just need to kludge those a a bit IRL. (This can also be reworked to be our normal basic filter)
7 U3B OPA1652470PF C17 C0G

DECISION - Two Choices: 1. Add LD1117 (or LP2985) or other 5V Linear Reg. 2. Power TPA6110 from Seed's 3v3A Gain is set to target +4dBu (maximum)

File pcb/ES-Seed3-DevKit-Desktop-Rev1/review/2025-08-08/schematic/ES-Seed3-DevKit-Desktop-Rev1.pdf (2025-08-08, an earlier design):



For this board we may want to use the inductor
if it helps avoid excess voltage drop..
It'd be nice to have the addt'l filter stage


by setting the address pins to a


I updated these to be gain of 2. However, I'm not really sure how the math works out for the other two values.. So, I may just need to kludge those a a bit IRL. (This can also be reworked to be our normal basic filter) C21

Gain is set to target +4dBu (maximum)

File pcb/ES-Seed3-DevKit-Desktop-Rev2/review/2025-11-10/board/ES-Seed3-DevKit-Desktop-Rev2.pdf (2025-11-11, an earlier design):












Layer Name B.Cu | Bottom Solder Mask F.Cu | Matte | Thickness (mm) | Black | 1 | 0 FR4 0 Black Dielectric


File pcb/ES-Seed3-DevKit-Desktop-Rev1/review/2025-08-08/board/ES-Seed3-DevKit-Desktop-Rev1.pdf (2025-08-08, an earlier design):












Material | 0 mm | Black | | 0 Top Solder Mask Loss Tangent 0 Black 0
copper | | | | | | 0 mm | | | 0 White 0

Type

1 F.Silkscreen
Bottom Solder | Mask Top Solder Paste F.Cu | | | | Matte F.Mask F.Paste | 0.035 mm | White Not specified

Screen | | 0.035 mm | | | | 0 Bottom Silk

1 Not specified


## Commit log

2025-08-04 starting point copied from Eurorack Devkit.
    [ES-Seed3-DevKit-Desktop-Rev1-B_Cu.gbl, ES-Seed3-DevKit-Desktop-Rev1-B_Fab.gbr, ES-Seed3-DevKit-Desktop-Rev1-B_Mask.gbs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]
2025-08-04 removed previous version production materials.
    [ES-Seed3-DevKit-Desktop-Rev1-B_Cu.gbl, ES-Seed3-DevKit-Desktop-Rev1-B_Fab.gbr, ES-Seed3-DevKit-Desktop-Rev1-B_Mask.gbs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]
2025-08-04 schematic is like 85% done.. just needs audio circuits, and opamp choice(s).
    [ES-Seed3-DevKit-Desktop-Rev1.kicad_sch, Seed3-DevKit-Desktop_1.kicad_sch, Seed3-DevKit-Desktop_2.kicad_sch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]
2025-08-07 sch complete (pending value changes to audio out circuit and ERC fixes), footprints set, ready for layout.
    [ES-Seed3-DevKit-Desktop-Rev1.kicad_pcb, ES-Seed3-DevKit-Desktop-Rev1.kicad_sch, Seed3-DevKit-Desktop_1.kicad_sch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]
2025-08-07 added missing audio page of sch
    [audio.kicad_sch]
2025-08-07 lsno ERC errors or warnings, the few leftover warnings are excluded with valid comments.
    [Seed3-DevKit-Desktop_1.kicad_sch, Seed3-DevKit-Desktop_2.kicad_sch, audio.kicad_sch]
2025-08-07 we've got a layout going
    [ES-Seed3-DevKit-Desktop-Rev1.kicad_pcb, Seed3-DevKit-Desktop_1.kicad_sch, Seed3-DevKit-Desktop_2.kicad_sch]
2025-08-07 everything on the board -- some fine tuning necessary, and then ready to route.
    [ES-Seed3-DevKit-Desktop-Rev1.kicad_pcb, Seed3-DevKit-Desktop_1.kicad_sch, Seed3-DevKit-Desktop_2.kicad_sch]
2025-08-08 pre-routing checkpoint.
    [ES-Seed3-DevKit-Desktop-Rev1.kicad_pcb, ES-Seed3-DevKit-Desktop-Rev1.kicad_sch, audio.kicad_sch]
2025-08-08 flipped SRs -- actual pre-route checkpoint.
    [ES-Seed3-DevKit-Desktop-Rev1.kicad_pcb]
2025-08-08 cleanup of gate input circuits to reduce surface area -- pre-route-checkpoint-final-final
    [ES-Seed3-DevKit-Desktop-Rev1.kicad_pcb]
2025-08-08 routed, productions mats, etc.
    [ES-Seed3-DevKit-Desktop-Rev1-B_Cu.gbl, ES-Seed3-DevKit-Desktop-Rev1-B_Fab.gbr, ES-Seed3-DevKit-Desktop-Rev1-B_Mask.gbs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]
2025-08-08 slight sch tweaks for better bom parsing on jlcpcb.
    [ES-Seed3-DevKit-Desktop-Rev1-B_Cu.gbl, ES-Seed3-DevKit-Desktop-Rev1-B_Fab.gbr, ES-Seed3-DevKit-Desktop-Rev1-B_Mask.gbs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]
2025-11-05 copied project to start rev2.
    [ES-Seed3-DevKit-Desktop-Rev2.kicad_pcb, ES-Seed3-DevKit-Desktop-Rev2.kicad_sch, Seed3-DevKit-Desktop_1.kicad_sch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]
2025-11-05 starting to add the boost circuit changes now that the easy stuff is done.
    [Seed3-DevKit-Desktop_1.kicad_sch]
2025-11-06 layout and routing for changes -- need to review, and make mats.
    [ES-Seed3-DevKit-Desktop-Rev2.kicad_pcb, Seed3-DevKit-Desktop_1.kicad_sch, audio.kicad_sch]
2025-11-06 updated prod setup to include render of 3d model in the review folders, and added initial review/prod package for review.
    [ES-Seed3-DevKit-Desktop-Rev2-B_Cu.gbl, ES-Seed3-DevKit-Desktop-Rev2-B_Fab.gbr, ES-Seed3-DevKit-Desktop-Rev2-B_Mask.gbs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]
2025-11-10 a few more changes, and regenerated production mats
    [ES-Seed3-DevKit-Desktop-Rev2-B_Cu.gbl, ES-Seed3-DevKit-Desktop-Rev2-B_Fab.gbr, ES-Seed3-DevKit-Desktop-Rev2-B_Mask.gbs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]
2025-11-10 updated values for CD4021, and regenerated mats.
    [ES-Seed3-DevKit-Desktop-Rev2-B_Cu.gbl, ES-Seed3-DevKit-Desktop-Rev2-B_Fab.gbr, ES-Seed3-DevKit-Desktop-Rev2-B_Mask.gbs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]
2025-11-26 saved rev2-as-rev3 for starting point of changes.
    [ES-Seed3-DevKit-Desktop-Rev3.kicad_pcb, ES-Seed3-DevKit-Desktop-Rev3.kicad_sch, Seed3-DevKit-Desktop_1.kicad_sch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]
2025-11-26 project properly renamed after opening.
    [ES-Seed3-DevKit-Desktop-Rev3.kicad_sch]
2025-12-03 schematic level changes for fixing CV idle offset, and audio whine tone.
    [ES-Seed3-DevKit-Desktop-Rev3.kicad_pcb, Seed3-DevKit-Desktop_1.kicad_sch, audio.kicad_sch]
2025-12-03 initial changes made. need feedback on silk screen.
    [ES-Seed3-DevKit-Desktop-Rev3-B_Cu.gbl, ES-Seed3-DevKit-Desktop-Rev3-B_Fab.gbr, ES-Seed3-DevKit-Desktop-Rev3-B_Mask.gbs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]
2025-12-08 updated changelog with rev3 changes, updated silkscreen for software pin mappings, and swapped DAC channels so the STM32 ch matches the names on the PCB.
    [ES-Seed3-DevKit-Desktop-Rev3.kicad_pcb, Seed3-DevKit-Desktop_1.kicad_sch]
2025-12-08 regenerated production mats.
    [ES-Seed3-DevKit-Desktop-Rev3-B_Cu.gbl, ES-Seed3-DevKit-Desktop-Rev3-B_Fab.gbr, ES-Seed3-DevKit-Desktop-Rev3-B_Mask.gbs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]
2025-12-10 added board characteristics, and regen'd prod
    [ES-Seed3-DevKit-Desktop-Rev3-B_Cu.gbl, ES-Seed3-DevKit-Desktop-Rev3-B_Fab.gbr, ES-Seed3-DevKit-Desktop-Rev3-B_Mask.gbs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]
2025-12-10 updated rev text.
    [ES-Seed3-DevKit-Desktop-Rev3-B_Cu.gbl, ES-Seed3-DevKit-Desktop-Rev3-B_Fab.gbr, ES-Seed3-DevKit-Desktop-Rev3-B_Mask.gbs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]
2026-03-23 partial directory update for cleanup of schematic comments after validating rev3 HW
    [Seed3-DevKit-Desktop_1.kicad_sch, audio.kicad_sch]
2026-06-25 Rev4 - added missing diode, regenerated review/production mats (#13)
    * rev4 - added missing diode, regenerated review/production mats
    * rebuild planes, and regen'd prod mats.
    * updated jobset for bom grouping, fixed gnd plane, regen gerbers.
    [ES-Seed3-Devkit-Desktop-Rev4-B_Cu.gbl, ES-Seed3-Devkit-Desktop-Rev4-B_Fab.gbr, ES-Seed3-Devkit-Desktop-Rev4-B_Mask.gbs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]
2026-10-06 New readme (#14)
    * Add README for Seed3 Desktop Dev Kit
    Add comprehensive documentation for the Seed3 Desktop Dev Kit, including features, specifications, getting started guide, hardware reference, and licensing information.
    * Fix gate input threshold and enhance power connection info
    Corrected gate input threshold value and updated power connection instructions.
    * Revise licensing and trademark information in README
    Updated the licensing information and trademark details for the Desktop Dev Kit. Clarified the open-source hardware definition and added specific terms regarding the use of the DAISY trademark.
    * Revise README setup instructions and links
    Updated links and descriptions in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
2026-11-03 resistor/cap eagle symbol replacements.
2026-11-03 removed eagle library dependencies, and updated board file to sync with sch updates (need to adjust some silk that moved).
2026-11-03 updated USB footprint and DRC settings to resolve errors.
